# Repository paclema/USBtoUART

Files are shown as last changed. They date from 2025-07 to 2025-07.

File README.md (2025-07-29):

# USBtoUART

A compact USB-C to UART bridge board based on the Silicon Labs CP2102N chip and featuring a dedicated XC6220B331ER LDO regulator, designed for debugging, programming, and serial communication with microcontrollers and embedded systems.

**Why this board?** Unlike typical USB-to-UART bridges, this board features a dedicated LDO regulator that supplies up to 1A at 3.3V, ensuring stable power delivery to the target board while providing reliable data communication.

<p align="center" width="100%">
  <a href="doc/v1.0/_DSC3896.JPG">
    USBtoUART
  </a>
</p>

| Top View | 3D Rendering | Bottom View |
|:---:|:---:|:---:|
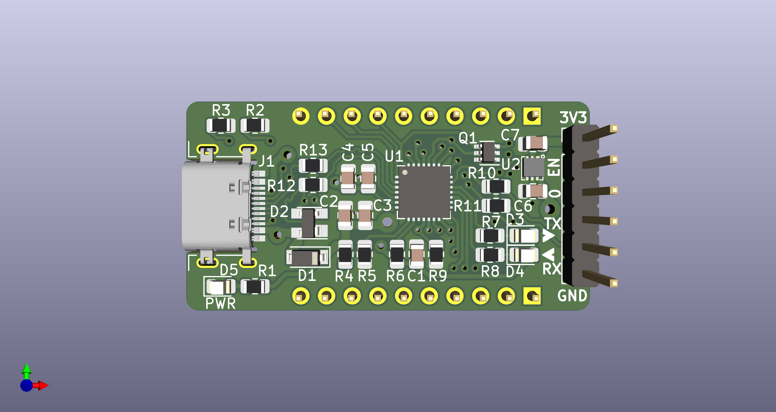
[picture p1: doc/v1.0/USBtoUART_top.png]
USBtoUART Top View
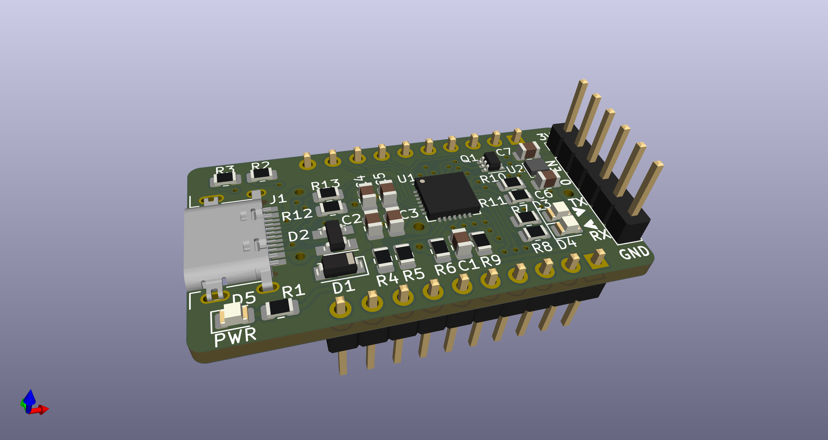
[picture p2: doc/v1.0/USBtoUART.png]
USBtoUART 3D View
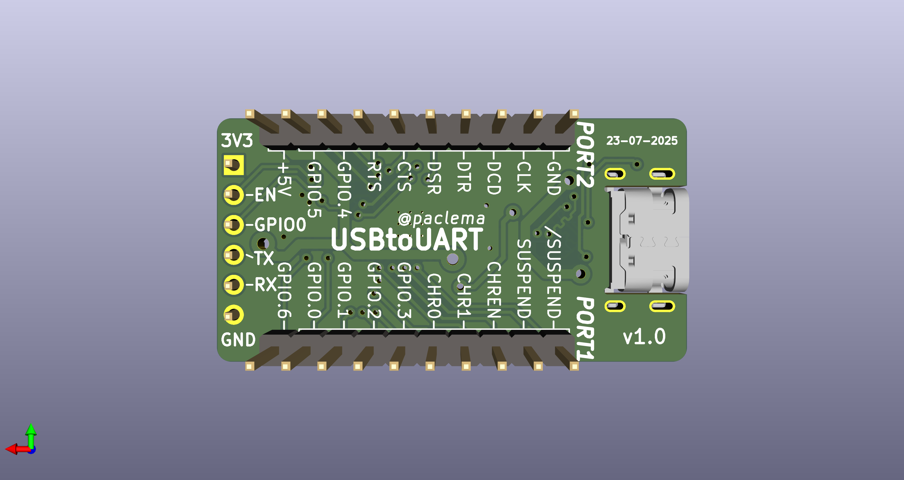
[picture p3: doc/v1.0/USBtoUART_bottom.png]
USBtoUART Bottom View
|  |  |  |

## Features

- **USB-C Connector**: Modern USB-C interface for reliable power and data connection (USB 2.0)
- **CP2102N Bridge Chip**: High-performance USB to UART bridge controller (up to 3 Mbaud)
- **High-Power LDO**: Dedicated XC6220B331ER regulator providing up to 1A at 3.3V for connected devices (the CP2102N operates directly from USB 5V)
- **Status LEDs**: Visual indicators for Power (PWR), Transmit (TX), and Receive (RX)
- **UART Breakout**: Dedicated 6-pin UART connector with standard pinout
- **Extended GPIO Access & Breadboard Compatibility**: Exposes extra CP2102N GPIO pins via dual 10-pin headers, designed for direct insertion into standard breadboards to simplify prototyping and expand control options
- **Auto-Reset Circuit**: Dual MOSFET transistor circuit enables automatic reset of the connected microcontroller during programming
- **Compact Form Factor**: Optimized 2-layer PCB layout with surface-mount components (0805 package size)

## Pin Configuration

### UART Connector (J3)
> **Note:** In ESP8266 and ESP32 family chips, their GPIO0 pin is used to control boot mode (e.g., entering flash mode for programming). The labeled GPIO0 pin in this connector is intended to be connected to the target chip's GPIO0 pin to control the boot mode. This usage may not apply to other target chips, so verify your specific hardware requirements.
> 
| Pin | Function | Description |
|-----|---|---|
| 1 | 3V3 | 3.3V Power Output |
| 2 | EN | Enable/Reset |
| 3 | GPIO0 | Boot mode control |
| 4 | TXD | UART Transmit |
| 5 | RXD | UART Receive |
| 6 | GND | Ground |

### Port Connectors (J2, J4)
- 10-pin male headers providing access to power rails (3.3V, 5V, GND) and CP2102N GPIO signals
- Enable powering and controlling external circuits directly from the board
- Compatible with standard breadboard and prototyping setups
- Standard 2.54mm (0.1") pin spacing

#### PORT1 Connector (J2)
| Pin | Function | Description |
|-----|---|---|
| 1 | GPIO.6 | CP2102N GPIO 6 |
| 2 | GPIO.0 | CP2102N GPIO 0 |
| 3 | GPIO.1 | CP2102N GPIO 1 |
| 4 | GPIO.2 | CP2102N GPIO 2 |
| 5 | GPIO.3 | CP2102N GPIO 3 |
| 6 | CHR0 | Battery Charging Detection 0 |
| 7 | CHR1 | Battery Charging Detection 1 |
| 8 | CHREN | Battery Charging Enable |
| 9 | SUSPEND  | USB Suspend State |
| 10  | /SUSPEND | USB Suspend State (Inverted) |

#### PORT2 Connector (J4)
| Pin | Function | Description |
|-----|---|---|
| 1 | +5V | 5V Power Output (from USB connector) |
| 2 | GPIO.5 | CP2102N GPIO 5 |
| 3 | GPIO.4 | CP2102N GPIO 4 |
| 4 | RTS | Request To Send |
| 5 | CTS | Clear To Send |
| 6 | DSR | Data Set Ready |
| 7 | DTR | Data Terminal Ready |
| 8 | DCD | Data Carrier Detect |
| 9 | CLK | Clock output |
| 10  | GND | Ground |

## Getting Started

### Driver Installation

Download and install the CP210x Universal Windows Driver:
[CP210x Universal Windows Driver](https://www.silabs.com/developers/usb-to-uart-bridge-vcp-drivers?tab=downloads)

### Connection

1. Connect your target device to the UART connector (J3) or port headers
2. Connect the USB-C cable to your computer
3. The PWR LED should illuminate, indicating successful power connection
4. TX/RX LEDs will flash during data transmission

### Device Configuration

The CP2102N chip allows customization of USB device descriptors including vendor ID, product ID, serial number, and other parameters:

#### Using Silicon Labs Simplicity Studio 5:
1. Download and install **Simplicity Studio 5** from [Silicon Labs](https://www.silabs.com/developers/simplicity-studio)
2. Connect the USBtoUART board to your computer
3. Launch Simplicity Studio 5 and select your CP2102N device from the detected devices list
4. Navigate to **USBXpress™ Device Configuratior** utility
5. Configure device descriptors (Product String, Vendor and Product IDs, Serial Number, etc.) and save them to the device

## Project Files

This repository containes:

- **KiCad Project**: [`USBtoUART.kicad_pro`](USBtoUART.kicad_pro) - Main KiCad project file
- **Schematics**: [`USBtoUART.kicad_sch`](USBtoUART.kicad_sch) - Complete circuit design
- **PCB Layout**: [`USBtoUART.kicad_pcb`](USBtoUART.kicad_pcb) - 2-layer PCB design
- **Custom Libraries**: [`libs/`](libs/) - Project-specific symbols, footprints, and 3D models
- **Bill of Materials**: [`bom/v1.0/USBtoUART.csv`](bom/v1.0/USBtoUART.csv) - Complete component list
- **Interactive BOM**: [`bom/v1.0/ibom.html`](bom/v1.0/ibom.html) - Interactive Bill of Materials
- **Gerber Files**: [`gerber/v1.0/`](gerber/v1.0/) - Manufacturing files
- **Documentation**: 
  - **Schematic PDF**: [`doc/v1.0/USBtoUART_sch.pdf`](doc/v1.0/USBtoUART_sch.pdf)
  - **PCB Layout PDFs**: [`doc/v1.0/USBtoUART_brd_top.pdf`](doc/v1.0/USBtoUART_brd_top.pdf), [`doc/v1.0/USBtoUART_brd_bottom.pdf`](doc/v1.0/USBtoUART_brd_bottom.pdf), [`doc/v1.0/USBtoUART_brd_layers.pdf`](doc/v1.0/USBtoUART_brd_layers.pdf)
  - **3D Model**: [`doc/v1.0/USBtoUART.step`](doc/v1.0/USBtoUART.step) - 3D model of the assembled USBtoUART board
  - **Board Images**: [`doc/v1.0/`](doc/v1.0/)

## Manufacturing

The board is designed for standard PCB manufacturing processes:
- **PCB Thickness**: 1.6mm
- **Minimum Track/Space**: 0.1mm/0.1mm
- **Minimum Via**: 0.2mm
- **Surface Finish**: HASL or ENIG recommended

## Version History

- **v1.0**: First release

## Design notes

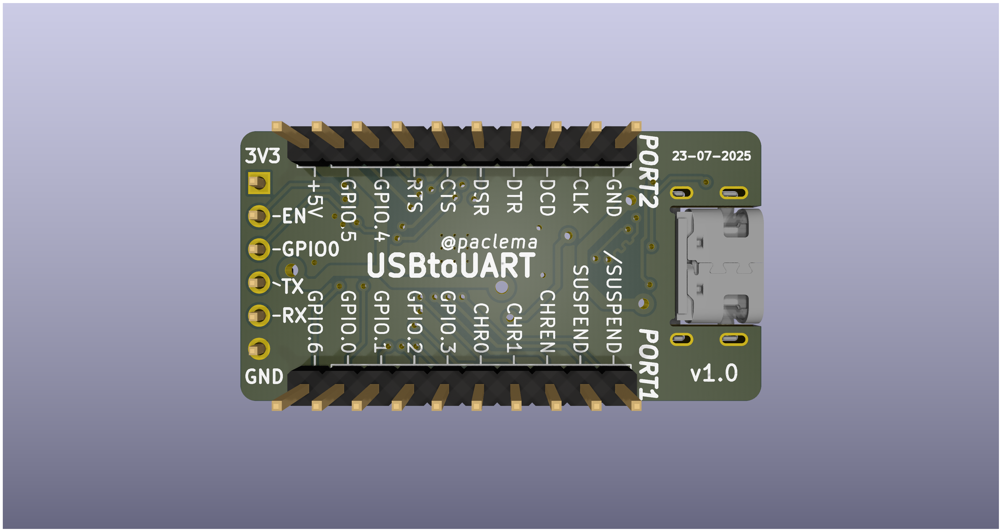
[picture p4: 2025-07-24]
doc/v1.0/USBtoUART_bottom_xray.png

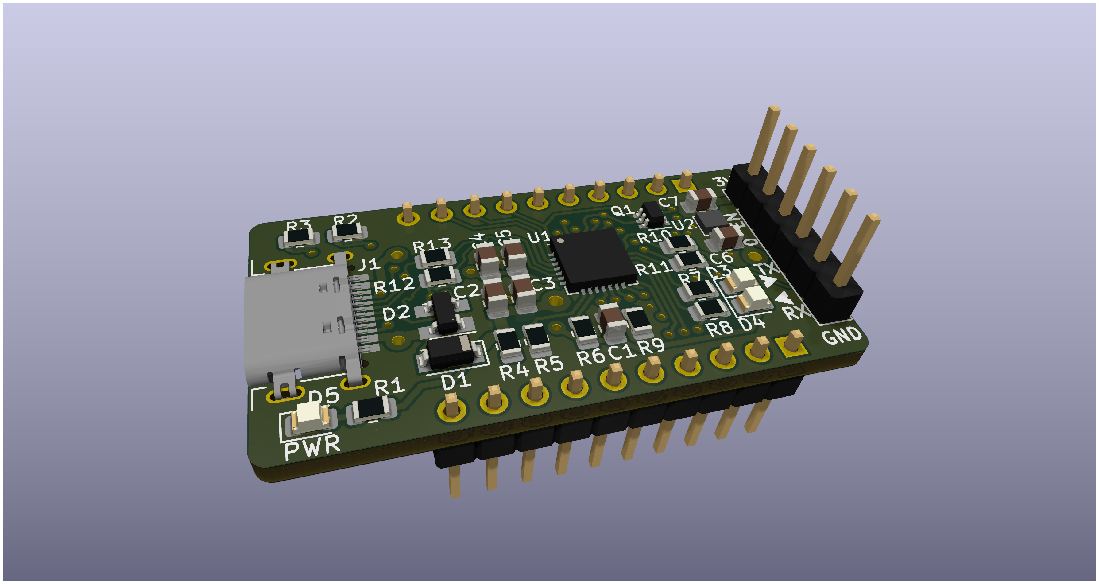
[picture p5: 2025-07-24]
doc/v1.0/USBtoUART_xray.png

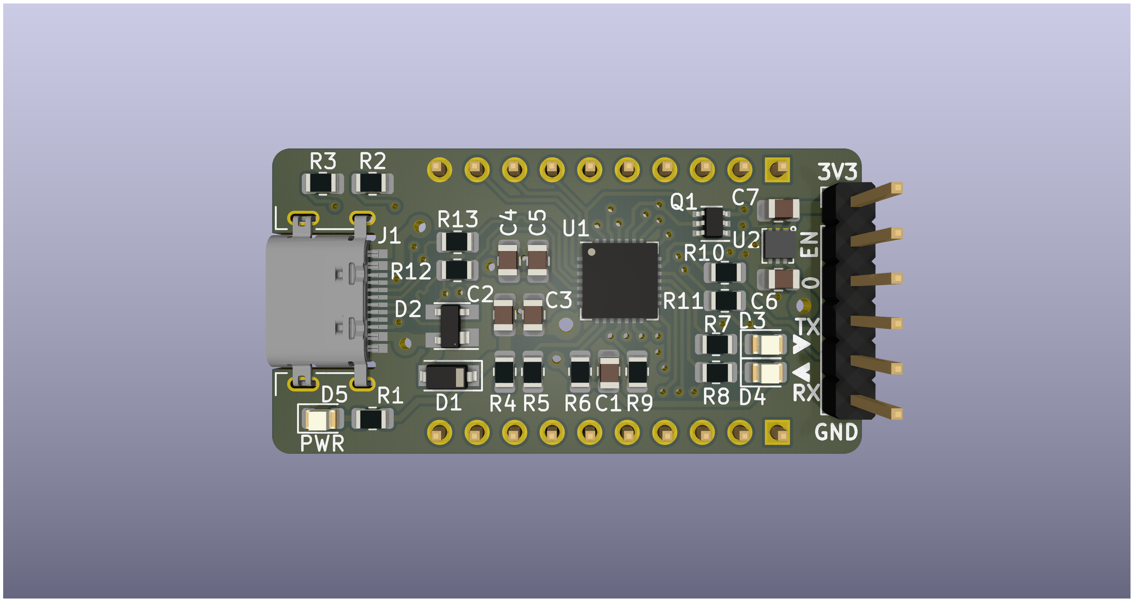
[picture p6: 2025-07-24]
doc/v1.0/USBtoUART_top_xray.png

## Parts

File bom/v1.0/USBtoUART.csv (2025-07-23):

# | Reference | Qty | Value | Footprint | DNP
1 | C1, C3, C4 | 3 | 0.1uF | Capacitor_SMD:C_0805_2012Metric
2 | C2, C5, C7 | 3 | 4.7uF | Capacitor_SMD:C_0805_2012Metric
3 | C6 | 1 | 22uF | Capacitor_SMD:C_0805_2012Metric
4 | D1 | 1 | SS14/1N5819/S4/BAT760-7 | USBtoUART:SOD-123EP
5 | D2 | 1 | SP0503BAHT | Package_TO_SOT_SMD:SOT-143
6 | D3 | 1 | TX | LED_SMD:LED_0805_2012Metric
7 | D4 | 1 | RX | LED_SMD:LED_0805_2012Metric
8 | D5 | 1 | PWR | LED_SMD:LED_0805_2012Metric
9 | J1 | 1 | USB_C_Receptacle_USB2.0 | USBtoUART:USB_C_Receptacle_Molex_216990-001
10 | J2 | 1 | PORT1 | Connector_PinHeader_2.54mm:PinHeader_1x10_P2.54mm_Vertical
11 | J3 | 1 | UART0 | Connector_PinHeader_2.54mm:PinHeader_1x06_P2.54mm_Vertical
12 | J4 | 1 | PORT2 | Connector_PinHeader_2.54mm:PinHeader_1x10_P2.54mm_Vertical
13 | Q1 | 1 | MUN5211DW1 | Package_TO_SOT_SMD:SOT-363_SC-70-6
14 | R1 | 1 | 2.2K | Resistor_SMD:R_0805_2012Metric
15 | R2, R3 | 2 | 5.1K | Resistor_SMD:R_0805_2012Metric
16 | R4 | 1 | 22.1K | Resistor_SMD:R_0805_2012Metric
17 | R5 | 1 | 47.5K | Resistor_SMD:R_0805_2012Metric
18 | R6 | 1 | 4.7K | Resistor_SMD:R_0805_2012Metric
19 | R7, R8 | 2 | 1K | Resistor_SMD:R_0805_2012Metric
20 | R9 | 1 | 10K | Resistor_SMD:R_0805_2012Metric
21 | R10, R11 | 2 | 470R | Resistor_SMD:R_0805_2012Metric
22 | R12, R13 | 2 | 22R | Resistor_SMD:R_0805_2012Metric
23 | U1 | 1 | CP2102N-Axx-xQFN28 | Package_DFN_QFN:QFN-28-1EP_5x5mm_P0.5mm_EP3.35x3.35mm_ThermalVias
24 | U2 | 1 | XC6220B331ER | USBtoUART:USP-6C

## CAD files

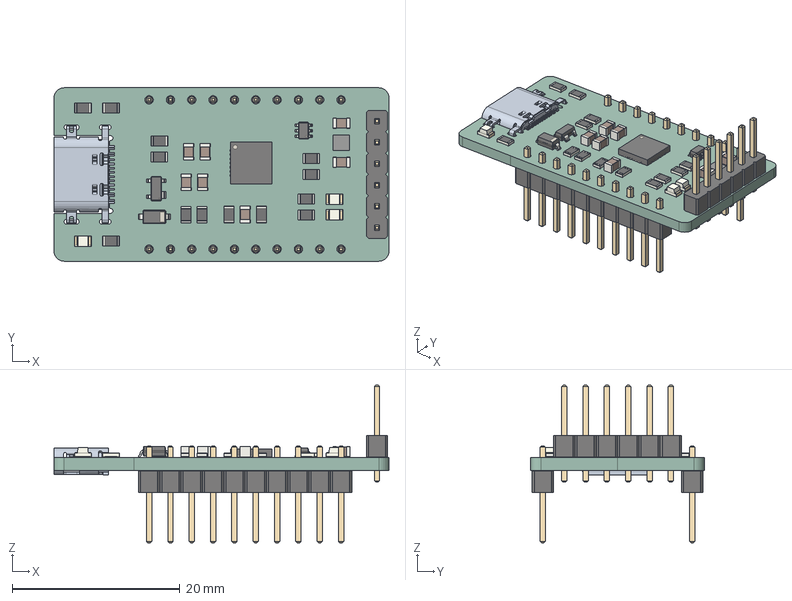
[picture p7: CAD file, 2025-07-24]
doc/v1.0/USBtoUART.step
39.9 x 20.7 x 18.8 mm
R_0805_2012Metric x 13
Pins
D_SOD-123
C_0805_2012Metric x 7
SOT-143
LED_0805_2012Metric x 3
QFN-28-1EP_5x5mm_P0.5mm_EP3.35x3.35mm
PinHeader_1x06_P2.54mm_Vertical
SOT-363_SC-70-6
PinHeader_1x10_P2.54mm_Vertical x 2
USBtoUART_PCB

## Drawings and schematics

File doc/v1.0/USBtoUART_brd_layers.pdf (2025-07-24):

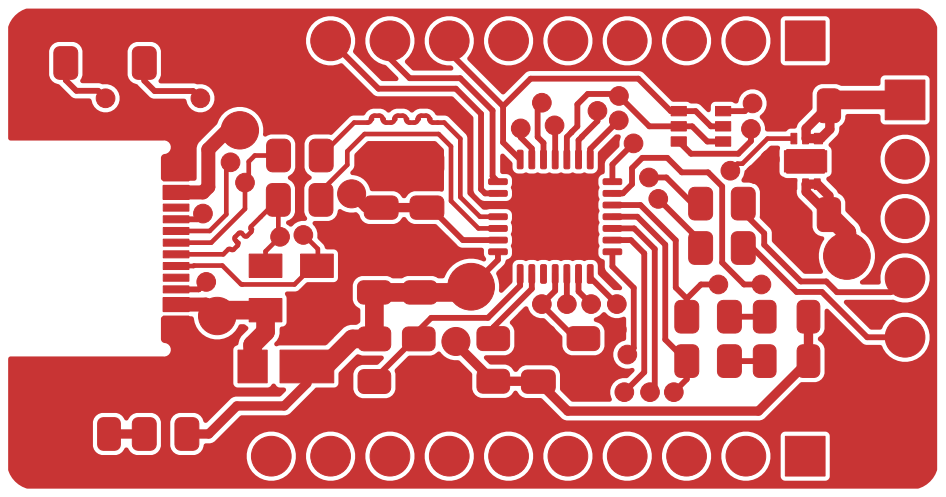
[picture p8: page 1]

github.com/paclema/USBtoUART

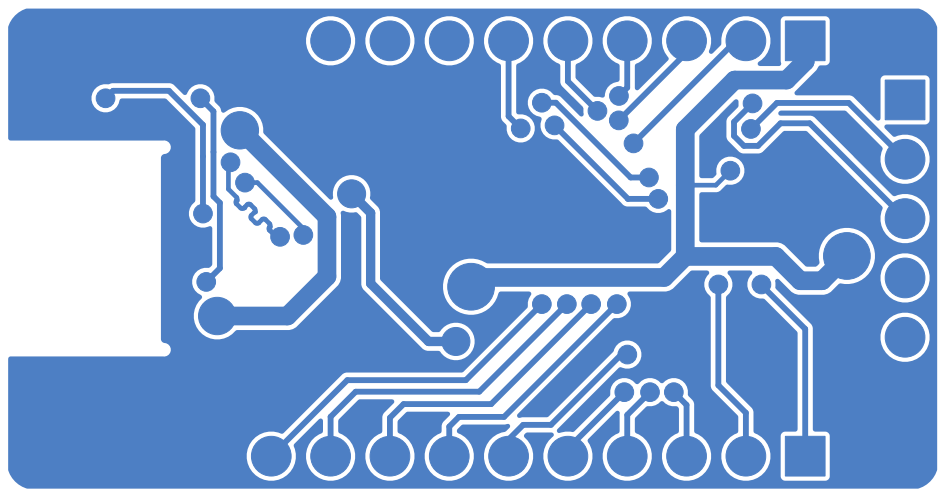
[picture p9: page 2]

github.com/paclema/USBtoUART

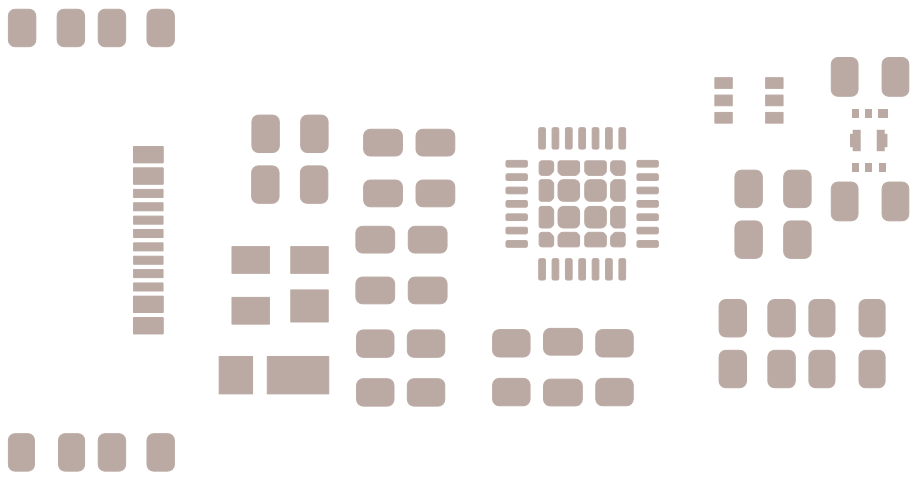
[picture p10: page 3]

github.com/paclema/USBtoUART

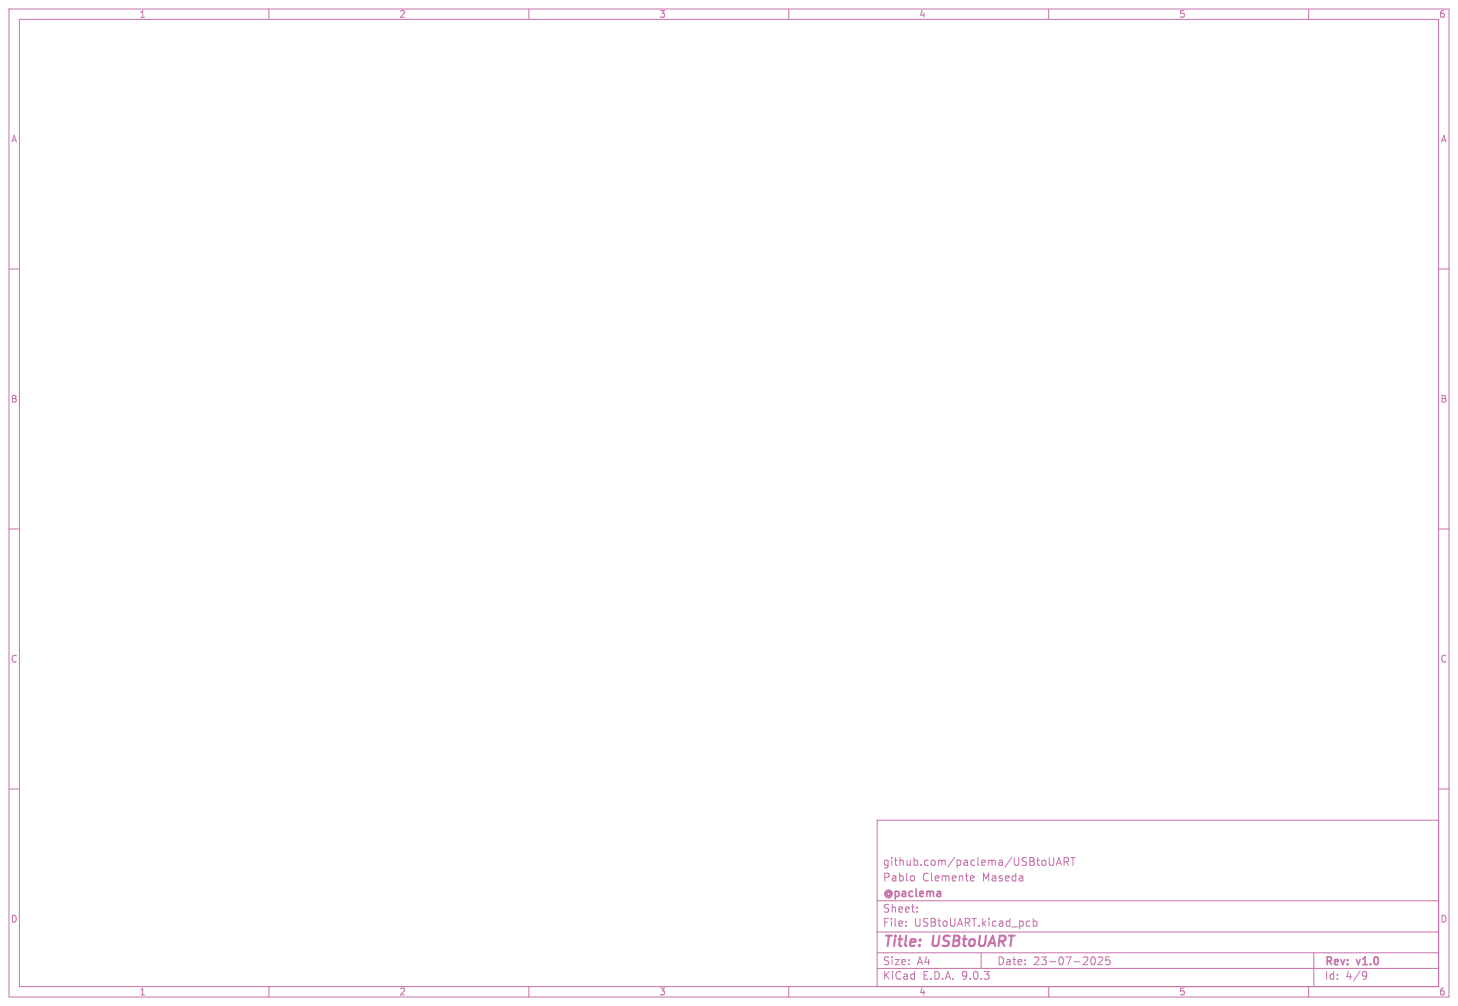
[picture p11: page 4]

github.com/paclema/USBtoUART

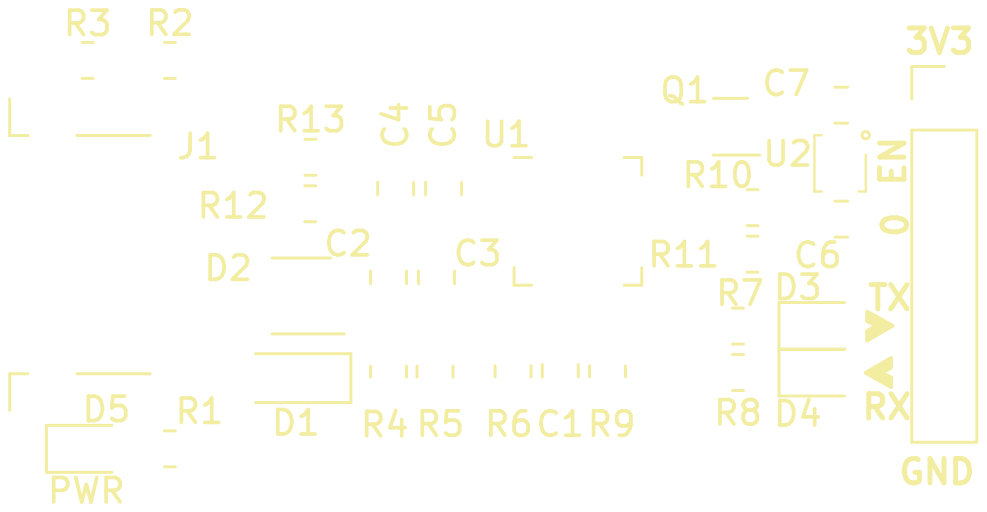
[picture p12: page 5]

github.com/paclema/USBtoUART EN 3V3 GND

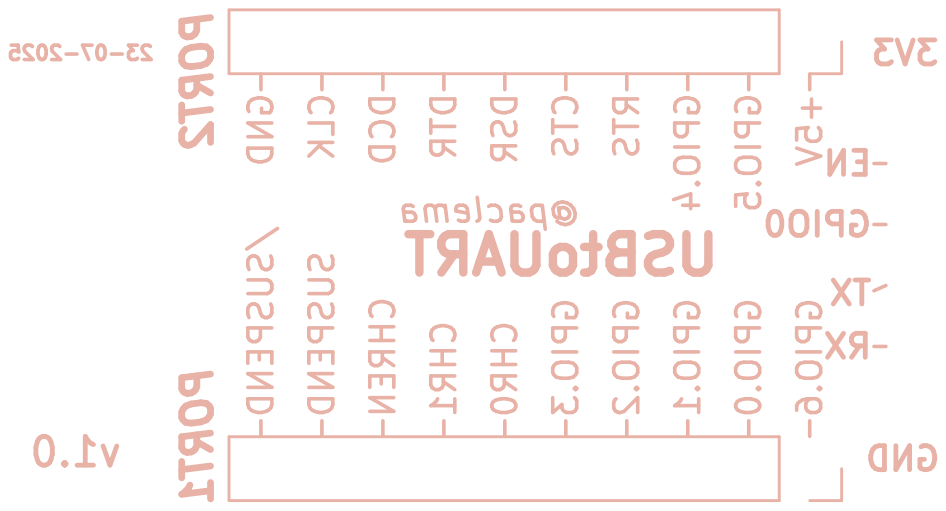
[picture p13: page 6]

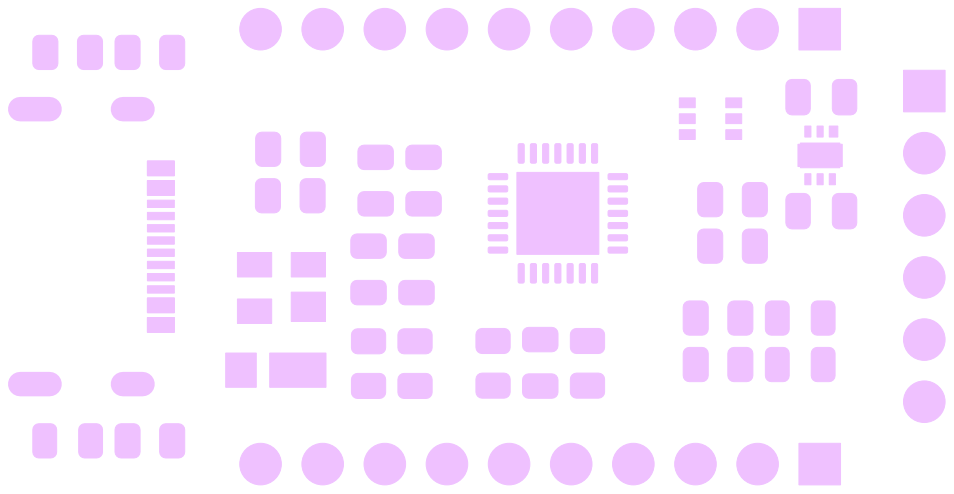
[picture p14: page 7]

github.com/paclema/USBtoUART

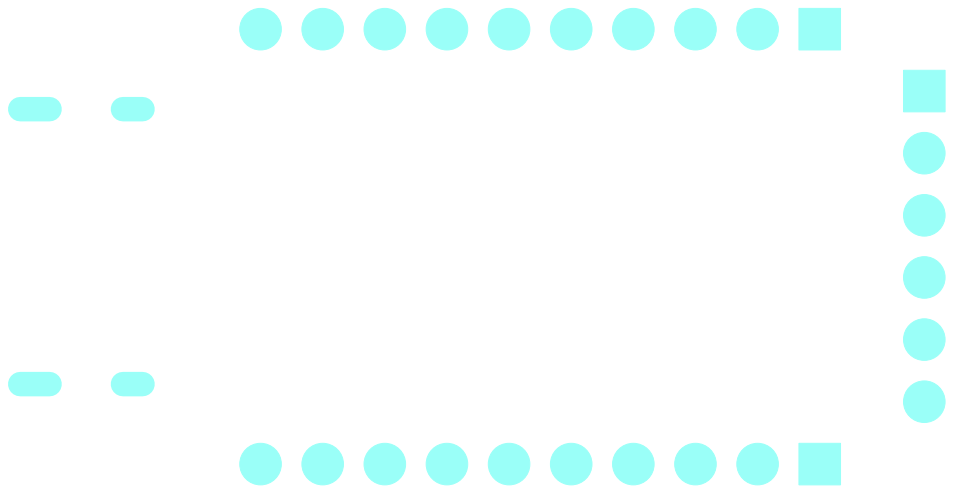
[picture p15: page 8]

github.com/paclema/USBtoUART

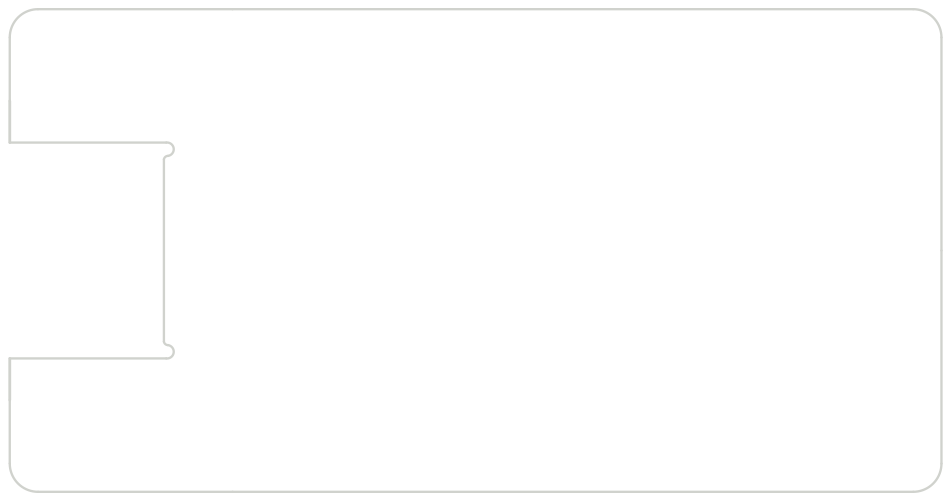
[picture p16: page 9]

github.com/paclema/USBtoUART

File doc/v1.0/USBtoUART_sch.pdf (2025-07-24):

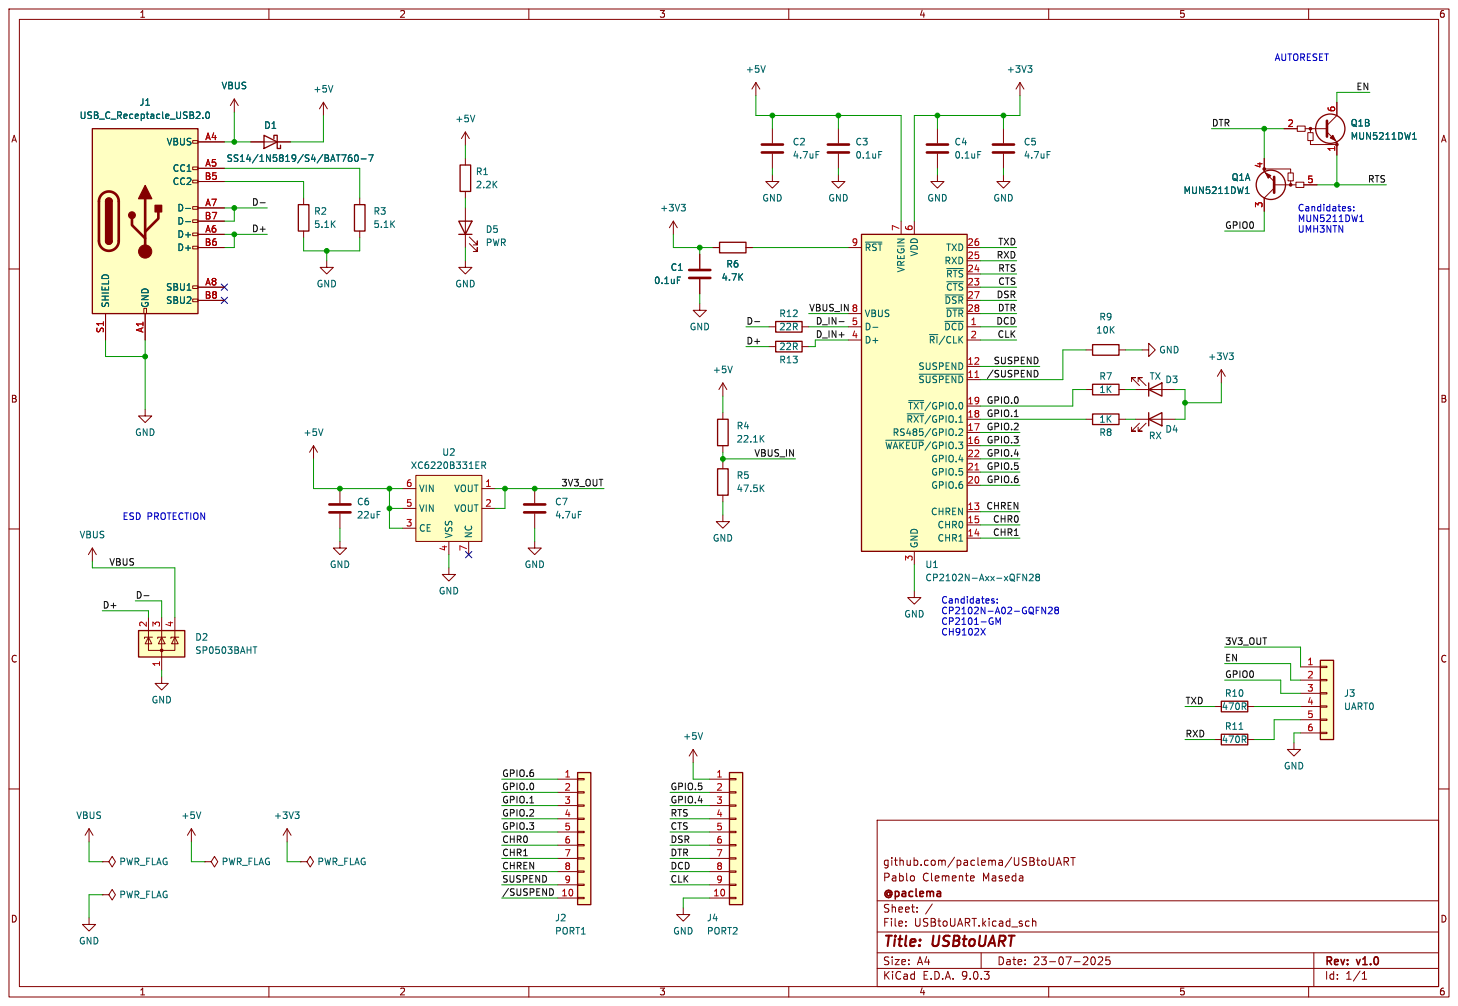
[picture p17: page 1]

3 4 Q1A MUN5211DW1 VIN 6 VIN 5 CE 3 VSS

3 TXD 26 RXD 25 ~{RTS} 24 ~{CTS} 23 ~{DSR} 27 ~{DTR} 28 ~{DCD}1 ~{RI}/CLK2 SUSPEND 12 ~{SUSPEND}11 ~{TXT}/GPIO.019 ~{RXT}/GPIO.118 RS485/GPIO.2 17 ~{WAKEUP}/GPIO.316 GPIO.4 22 GPIO.5 21 GPIO.6 20 CHREN 13 CHR0 15 CHR1 14 U1 CP2102N-Axx-xQFN28 R10

CTS GPIO.5 CHR0 GPIO.3 GPIO.2 CHR1

github.com/paclema/USBtoUART

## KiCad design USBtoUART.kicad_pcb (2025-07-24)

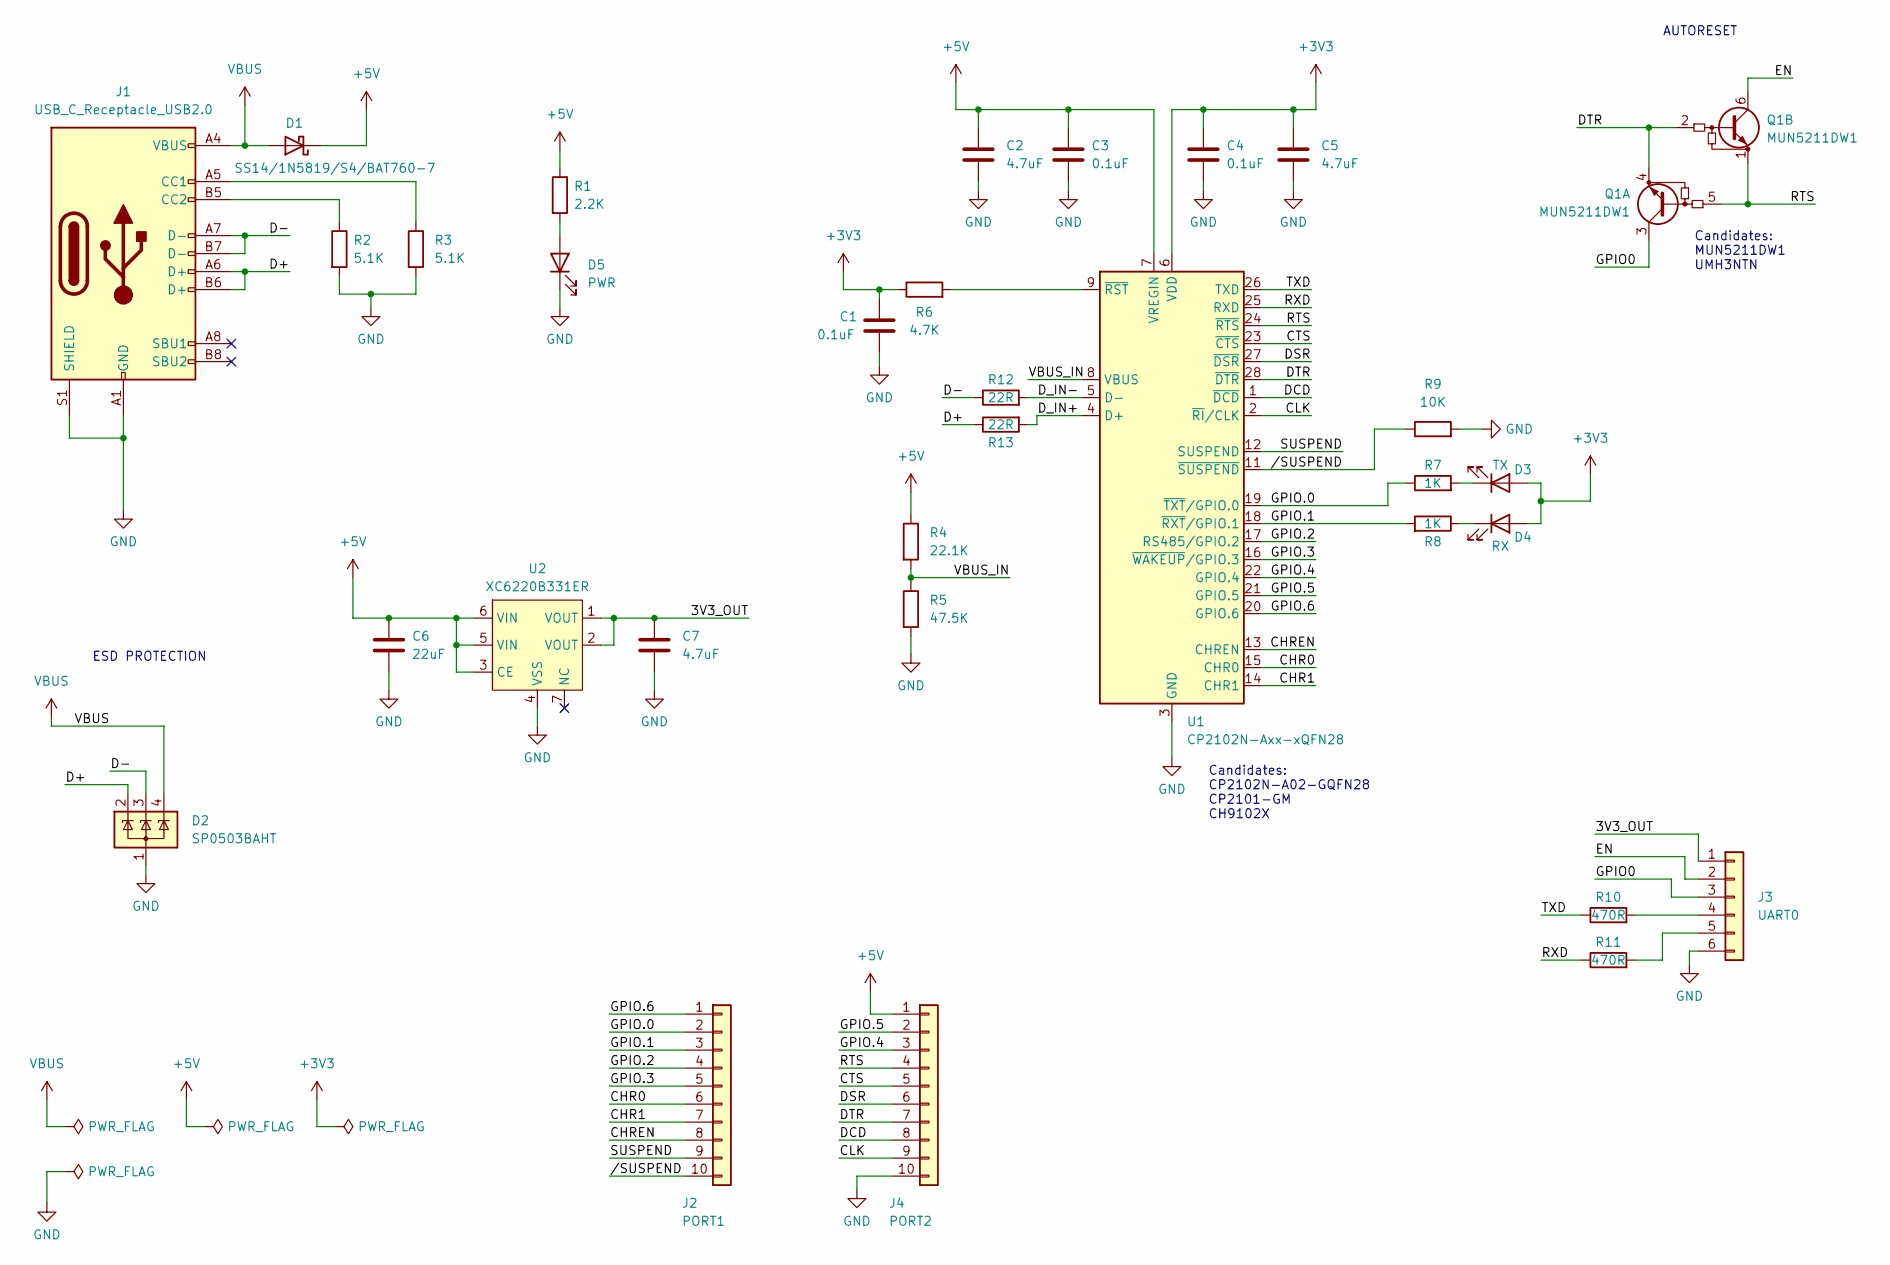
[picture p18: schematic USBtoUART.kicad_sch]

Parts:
C1, C3, C4: 0.1uF; C_0805_2012Metric; Mouser PN C0805C104K5RAC7411
C2, C5, C7: 4.7uF; C_0805_2012Metric; Mouser PN GRM21BR71C475KE51L
C6: 22uF; C_0805_2012Metric; Mouser PN GRM21BD71A226ME44L
D1: SS14/1N5819/S4/BAT760-7; SOD-123EP; Mouser PN SS14FP
D2: SP0503BAHT; SOT-143; Mouser PN SP0503BAHTG
D3: TX; LED_0805_2012Metric; Mouser PN LTST-C170GKT
D4: RX; LED_0805_2012Metric; Mouser PN LTST-C170KFKT
D5: PWR; LED_0805_2012Metric; Mouser PN 150080BS75000
J1: USB_C_Receptacle_USB2.0; USB_C_Receptacle_Molex_216990-001; Mouser PN 216990-0001
J2: PORT1; PinHeader_1x10_P2.54mm_Vertical
J3: UART0; PinHeader_1x06_P2.54mm_Vertical
J4: PORT2; PinHeader_1x10_P2.54mm_Vertical
Q1: MUN5211DW1; SOT-363_SC-70-6; Mouser PN MUN5211DW1T1G
R1: 2.2K; R_0805_2012Metric; Mouser PN AC0805FR-072K2L
R2, R3: 5.1K; R_0805_2012Metric; Mouser PN AC0805FR-075K1L
R4: 22.1K; R_0805_2012Metric; Mouser PN AC0805FR-0722K1L
R5: 47.5K; R_0805_2012Metric; Mouser PN AC0805FR-7W47K5L
R6: 4.7K; R_0805_2012Metric; Mouser PN AC0805FR-074K7L
R7, R8: 1K; R_0805_2012Metric; Mouser PN AC0805FR-071KL
R9: 10K; R_0805_2012Metric; Mouser PN AC0805FR-7W10KL
R10, R11: 470R; R_0805_2012Metric; Mouser PN AC0805FR-07470RL
R12, R13: 22R; R_0805_2012Metric; Mouser PN AC0805FR-0722RL
U1: CP2102N-Axx-xQFN28; QFN-28-1EP_5x5mm_P0.5mm_EP3.35x3.35mm_ThermalVias; Mouser PN CP2102N-A02-GQFN28
U2: XC6220B331ER; USP-6C; Mouser PN XC6220B331ER-G

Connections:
+3V3: C1.1, C4.1, C5.1, D3.2 (A), D4.2 (A), R6.1, U1.6 (VDD)
+5V: C2.1, C3.1, C6.1, D1.1 (K), J4.1, R1.1, R4.1, U1.7 (VREGIN), U2.3 (CE), U2.5 (VIN), U2.6 (VIN)
/3V3_OUT: C7.1, J3.1, U2.1 (VOUT), U2.2 (VOUT)
/CHR0: J2.6, U1.15 (CHR0)
/CHR1: J2.7, U1.14 (CHR1)
/CHREN: J2.8, U1.13 (CHREN)
/CLK: J4.9, U1.2 (~RI/CLK)
/CTS: J4.5, U1.23 (~CTS)
/D+: D2.2 (K), J1.A6 (D+), J1.B6 (D+), R13.1
/D-: D2.3 (K), J1.A7 (D-), J1.B7 (D-), R12.1
/DCD: J4.8, U1.1 (~DCD)
/DSR: J4.6, U1.27 (~DSR)
/DTR: J4.7, Q1.2 (B2), Q1.4 (E1), U1.28 (~DTR)
/D_IN+: R13.2, U1.4 (D+)
/D_IN-: R12.2, U1.5 (D-)
/EN: J3.2, Q1.6 (C2)
/GPIO0: J3.3, Q1.3 (C1)
/GPIO.0: J2.2, R7.1, U1.19 (~TXT/GPIO.0)
/GPIO.1: J2.3, R8.2, U1.18 (~RXT/GPIO.1)
/GPIO.2: J2.4, U1.17 (RS485/GPIO.2)
/GPIO.3: J2.5, U1.16 (~WAKEUP/GPIO.3)
/GPIO.4: J4.3, U1.22 (GPIO.4)
/GPIO.5: J4.2, U1.21 (GPIO.5)
/GPIO.6: J2.1, U1.20 (GPIO.6)
/RTS: J4.4, Q1.1 (E2), Q1.5 (B1), U1.24 (~RTS)
/RXD: R11.1, U1.25 (RXD)
/SUSPEND: J2.9, U1.12 (SUSPEND)
/TXD: R10.1, U1.26 (TXD)
/VBUS_IN: R4.2, R5.1, U1.8 (VBUS)
//SUSPEND: J2.10, R9.1, U1.11 (~SUSPEND)
GND: C1.2, C2.2, C3.2, C4.2, C5.2, C6.2, C7.2, D2.1 (A), D5.1 (K), J1.A1 (GND), J1.A12 (GND), J1.B1 (GND), J1.B12 (GND), J1.S1 (SHIELD), J3.6, J4.10, R2.2, R3.2, R5.2, R9.2, U1.3 (GND), U1.29 (GND), U2.4 (VSS)
unnamed: D3.1 (K), R7.2
unnamed: D4.1 (K), R8.1
unnamed: D5.2 (A), R1.2
unnamed: J1.A5 (CC1), R3.1
unnamed: J1.B5 (CC2), R2.1
unnamed: J3.4, R10.2
unnamed: J3.5, R11.2
unnamed: R6.2, U1.9 (~RST)
VBUS: D1.2 (A), D2.4 (K), J1.A4 (VBUS), J1.A9 (VBUS), J1.B4 (VBUS), J1.B9 (VBUS)

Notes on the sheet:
Candidates: MUN5211DW1 UMH3NTN
Candidates: CP2102N-A02-GQFN28 CP2101-GM CH9102X
AUTORESET
ESD PROTECTION

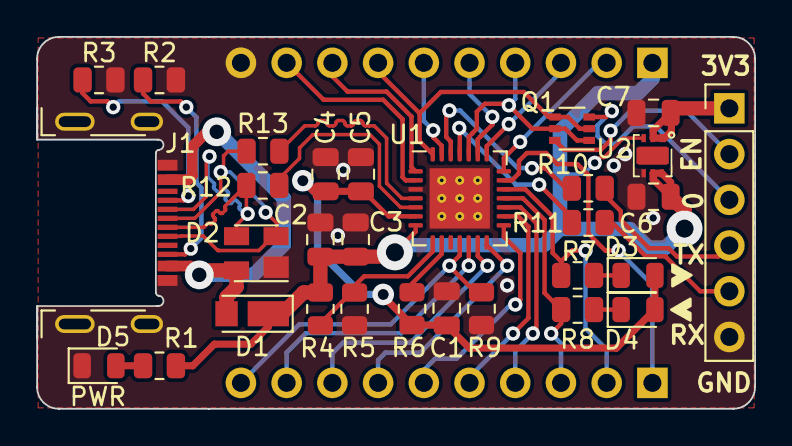
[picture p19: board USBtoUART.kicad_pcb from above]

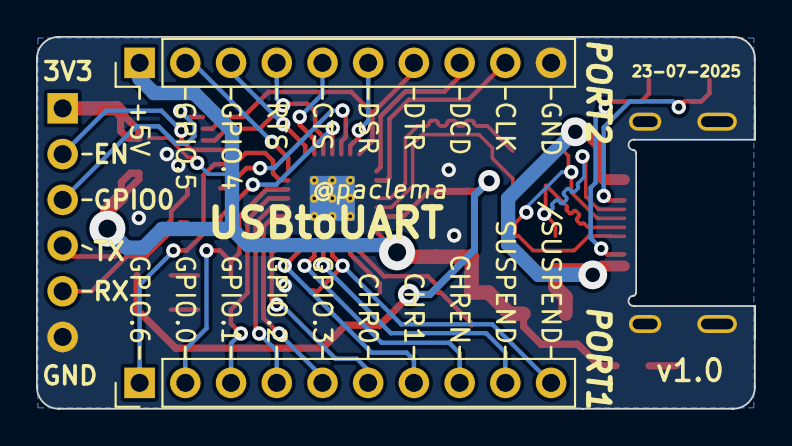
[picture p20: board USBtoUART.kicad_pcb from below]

Board: 2 copper layers, 39.9 x 20.7 mm, 32 parts (2 on the bottom side), 40 nets.

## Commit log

2025-07-23 Add USBtoUART sch, pcb, symbols, footprints, 3d models and bom for version v1.0
    [USBtoUART.csv, USBtoUART.kicad_pcb, USBtoUART.kicad_sch]
2025-07-23 Update README.md for CP210x Universal Windows Driver
2025-07-24 Add doc files including exported pdf for sch & brd and images for USBtoUART v1.0
    [USBtoUART.kicad_pcb, USBtoUART.step]
2025-07-24 Export gerber files for USBtoUART v1.0
    [USBtoUART-B_Cu.gbl, USBtoUART-B_Mask.gbs, USBtoUART-B_Paste.gbp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]
2025-07-24 Update README.md to enhance board description, features, and usage instructions for USBtoUART
2025-07-29 Add real image of USBtoUART board to README.md
2025-07-29 Update 3D files with routing and silkscreen
